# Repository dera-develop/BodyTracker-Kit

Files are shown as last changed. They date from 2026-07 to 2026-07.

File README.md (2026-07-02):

# BODY TRACKER  
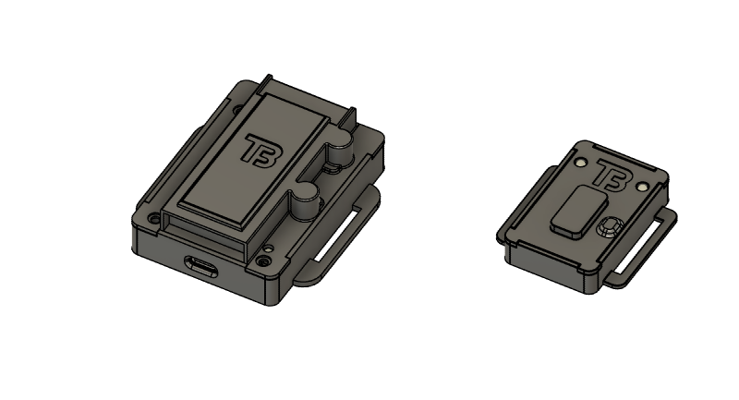
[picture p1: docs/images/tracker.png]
トラッカー
  
自作のトラッカーです．[SlimeVR](https://github.com/SlimeVR/SlimeVR-Server)を使用します．  
データの取得方法で迷走して，完成まで2か月くらいかかりました．  
ドリフトの時間サイクルは体感30分程度です．  

## 概要  
**LSM6DSV16X** のSFLPで出力されたクオータニオンを **ESP32-WROOM-32E** でI2C経由で拾ってSlimeVRに送信します．  

このトラッカーはマスターとスレーブの2個セットで製作されており，このセンサーを複数セット製作し接続することで，トラッキング箇所を自由に増やすことができます．  

詳細の仕様についてのドキュメントは[こちら](docs/overview.md)をご覧ください．  
製作手順については[こちら](docs/setup.md)をご覧ください．  

## 免責
本プロジェクトは以下の外部ソフトウェア・環境を利用しています．  
本リポジトリ内に同包はしていません．  
  
- SlimeVR Server  
[SlimeVR Server リポジトリ](https://github.com/SlimeVR/SlimeVR-Server)  
*本プロジェクトはSlimeVRのシステムと互換性を持つよう設計されていますが，SlimeVRチームによって作成，提供，または承認されたものではありません．*  
*「SlimeVR」は，SlimeVR BVの商標または登録商標です．*  
  
- Arduino  
[Arduino.cc](https://www.arduino.cc/)  
*本プロジェクトはArduino環境を利用していますが，Arduino公式プロジェクトとは無関係です．*  
*「Arduino(R)」は，Arduino Srlの商標または登録商標です．*

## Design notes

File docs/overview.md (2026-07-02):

# OVERVIEW  
トラッカーに関する詳細ドキュメントです．  

## 全体  
VRChatで使用することを前提として作成した，ボディートラッカーのセンサー2個セットです．  
モバイルバッテリー等の5V供給が出来るUSB電源を使用することで動作させることができます．  

製作する際は，[トラッカーの作り方](setup.md)を一読してください．製作手順と注意事項等が書いてあります．  

### 使用モジュール  
このトラッカーは，以下のIMUセンサーとマイコンを使用しています．  
|機器|名前|販売ページ(秋月電子通商)  
|---|---|---|
|IMUセンサー|LSM6DSV16X|[6軸IMUセンサーモジュール](https://akizukidenshi.com/catalog/g/g130950/)|  
|マイコン|ESP32-WROOM-32E|[ESP32-WROOM-32Eマイコンボード](https://akizukidenshi.com/catalog/g/g116108/)|  

表面実装が難しかったため，秋月電子通商で販売されているDPI化されているものを使用しています．  

### 構成  
構成は下図のようになっています．  
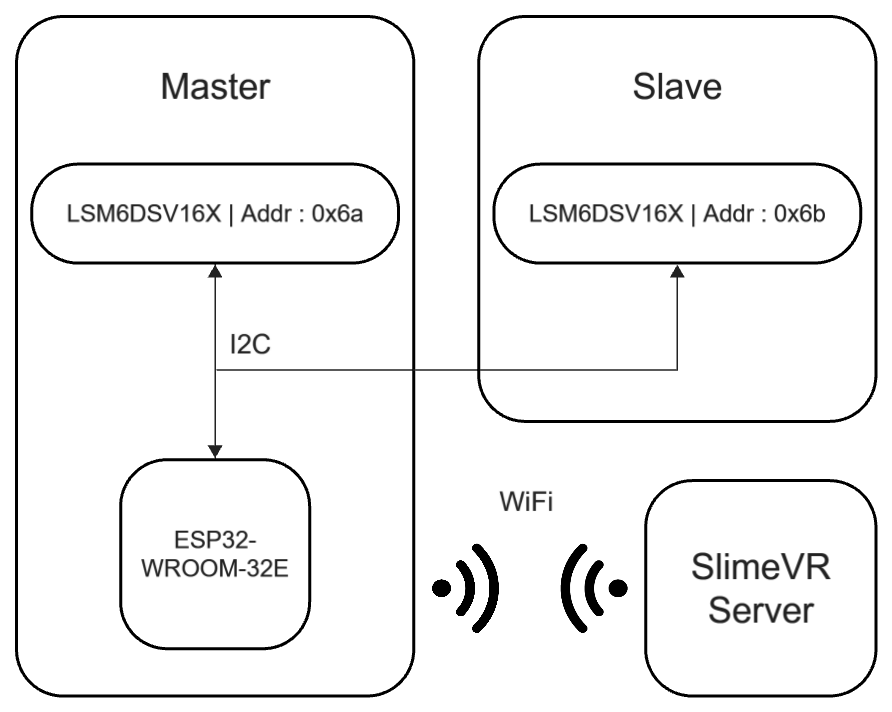
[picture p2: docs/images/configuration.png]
構成図
  

このトラッカーはマスターとスレーブに分かれており，I2Cで接続されています．  
相互の接続にはUSBのCtoCケーブルを使用します．  

#### プログラムの構成  
トラッカーのプログラムは，[prg/Firmware/BT_v4](../prg/Firmware/BT_v4/)に置いてあります．  
```  
BT_v4  
├── src/  
│   ├── I2Ccontroller.h  
│   ├── I2Ccontroller.cpp  
│   ├── IMUcontroller_I2C.h  
│   ├── IMUcontroller_I2C.cpp  
│   ├── Network_Connectioninfo_sample.h  
|   |     (実際のプログラムではNetwork_Connectioninfo.hを使用します)  
│   ├── UDPpackage.h  
│   └── UDPpackageV2.cpp  
└── BT_v4.ino  
```  
それぞれの内容は，ファイル名通りです．  
詳細は各ヘッダファイルを確認してください．  

### 動作  
電源スイッチが無く，USBケーブルを電源側に接続した時点で電源が入ります．  
（電源ポートとスレーブとの通信ポートは別物です．通信ポートに5Vを入力した場合，扱う電圧レベルが異なるため故障する可能性があります．）  
電源投入後，次の流れで動作します．  

#### 1, 初期設定  
始めにIMUセンサーの初期化を行います．IMUセンサー内にある **Who am I レジスタ(0x0f)** を参照し，値が読み取れた場合に初期化を行います．  
レジスタの初期化は，  
```  
prg/Firmware/BT_v4/src/IMUcontroller_I2C.cpp  
```  
内にある  
```cpp  
IMUcontroller_I2C::init(...)  
```  
関数内で実行されています．  
どのレジスタにどのデータを設定しているのかは，ここを参照することで確認できます．  

#### 2, WiFi接続  
プログラム内で設定されている情報を使い，WiFiネットワークに接続します．  
```cpp  
/* prg/Firmware/BT_v4/src/Network_Connectioninfo.h */  

namespace Network_ConnectionInfo{  
  inline constexpr char* WiFi_SSID = "WIFI_SSID";      // WiFi-SSID  
  inline constexpr char* WiFi_PASS = "WIFI_PASS";      // WiFi-PASS  
  ...  
}  
```  
同ディレクトリ内に **Network_Connectioninfo_sample.h** というファイルがあるので，このファイルの設定を変更し，名前を変更したうえで書き込みを行ってください．  

#### 3, サーバーハンドシェイク  
WiFiへ接続後，ハンドシェイクを送信します．  
```cpp  
/* prg/Firmware/BT_v4/src/Network_Connectioninfo.h */  

namespace Network_ConnectionInfo{  
  ...  
  inline constexpr char* SERVER_ADDR = "SERVER_IP_ADDRESS";    // SlimeVR-Server-IPAddress  
  inline constexpr int   SERVER_PORT = 6969;  // SlimeVR-Server-port  
}  
```  
ハンドシェイクパケットは2秒ごとに送信されます．（ステータスLEDの表示が約2000msのため）  
送信後ハンドシェイクACKを受信するまで繰り返されます．  

また，ハンドシェイクの試行回数は上限を設定でき，  
```cpp  
/* prg/Firmware/BT_v4/BT_v4.ino */  

const uint8_t   NW_WIFI_TIMEOUT = 100;  // WiFi timeout  
```  
で設定が可能です．最大値は **255** です．  
上限に達するとステータスLEDがエラー表示の点滅を行うようになり，それ以降の処理が行われません．  

#### 4, センサー情報の送信  
センサーの情報が送信されます．  

#### 5, センサーデータの送信  
ここがトラッキングのメインプロセスです．  
センサーの値を取得し，データをSlimeVR Serverへ送信します．  

FIFOの更新レートは120Hzに設定されており，新しいデータが届き次第パケットが送信されます．  

また，3秒ごとにステータスLEDが点滅します．

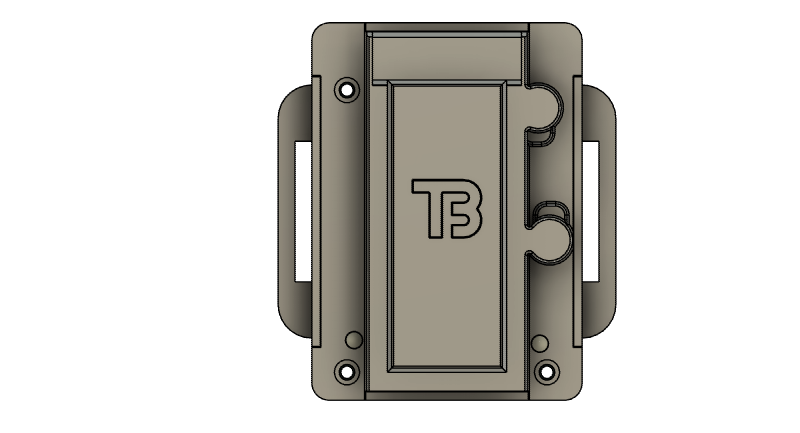
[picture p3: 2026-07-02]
docs/images/master_case_angle.png

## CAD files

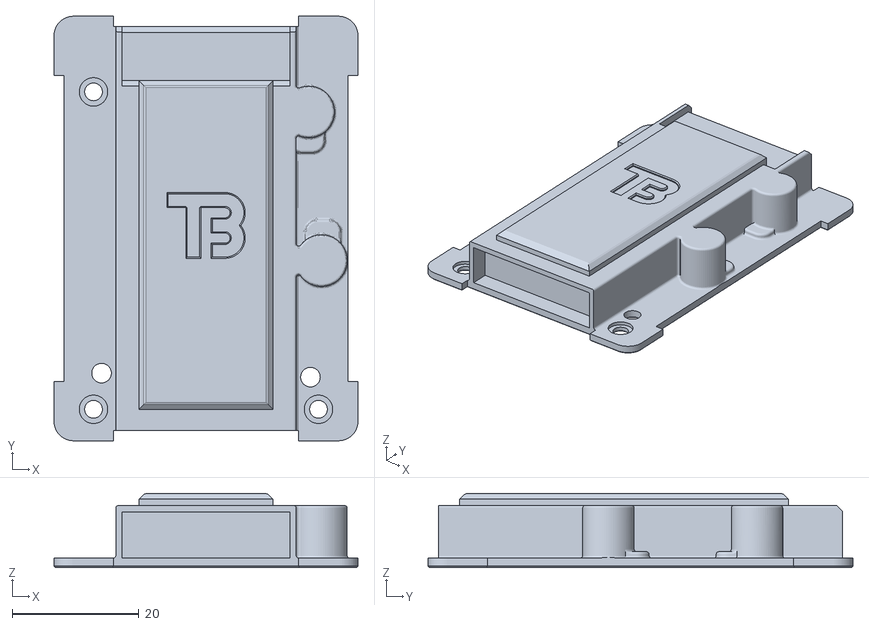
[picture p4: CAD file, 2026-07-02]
case/master/lid.stl
48.0 x 67.1 x 11.7

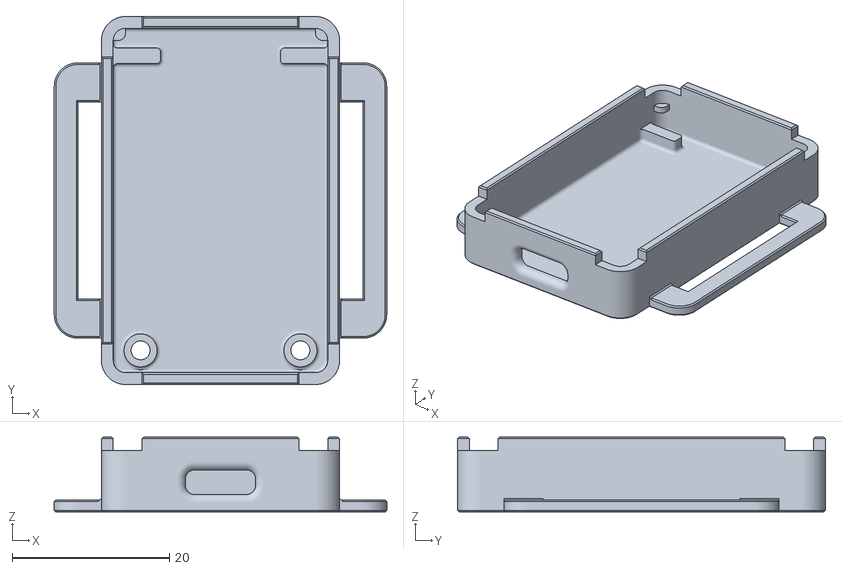
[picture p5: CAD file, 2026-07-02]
case/slave/box.stl
42.3 x 46.8 x 9.50

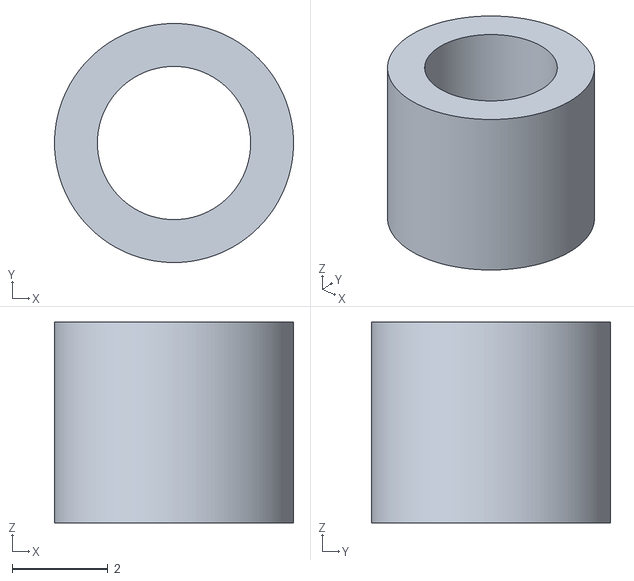
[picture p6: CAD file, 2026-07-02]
case/master/spacer.stl
5.00 x 5.00 x 4.20

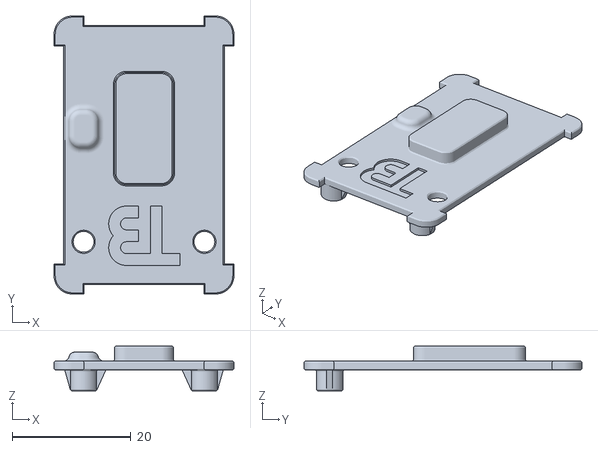
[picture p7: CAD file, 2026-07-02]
case/slave/lid.stl
30.3 x 46.8 x 7.50

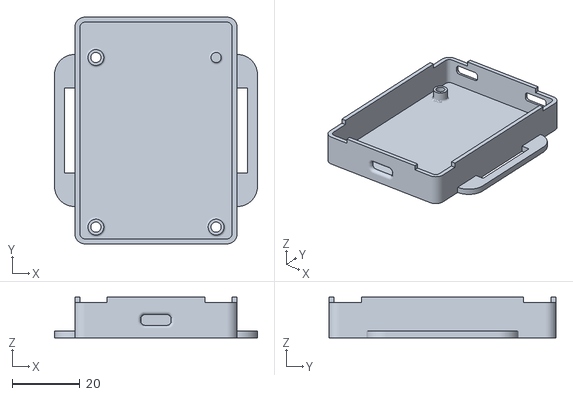
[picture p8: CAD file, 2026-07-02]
case/master/box.stl
60.0 x 67.1 x 12.0

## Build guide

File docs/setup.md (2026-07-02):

# トラッカーの作り方  
このトラッカーの作り方の手順を説明していきます．  

## 免責  
本ドキュメントに記載されているトラッカーの作成・使用・その他の利用によって生じた全ての損害，損失，トラブル等について，作者は一切の責任を負いません．また，いかなる保証やサポートも提供しません．  
本ツールの利用はすべて利用者自身の判断と責任において行ってください．  

## 必要なもの  
以下の部品を準備します．  
|名称|個数|販売ページ|  
|--|-:|--|
|ESP32-WROOM-32E|x1|[ESP32-WROOM-32E](https://akizukidenshi.com/catalog/g/g116108/)|  
|LSM6DSV16X|x1|[LSM6DSV16X](https://akizukidenshi.com/catalog/g/g130950/)|  
|ピンソケット 1x16p|x2|-|  
|電源専用USB-Cコネクタ|x2|[電源供給用TypeCコネクタ](https://akizukidenshi.com/catalog/g/g116895/)|  
|USB-Cコネクタ|x2|[ミッドマウントTypeCコネクタ](https://akizukidenshi.com/catalog/g/g113235/)|  
|φ3mm LED VF2.8 20mA|x4|-|  
|3.3V 3端子レギュレーター|x1|[3.3V-1A レギュレーター](https://akizukidenshi.com/catalog/g/g102252/)|  
|カーボン抵抗 1/4W 2kΩ|x4|-|  
|積層セラミックコンデンサ 0.1uF|x5|-|  
|アルミ電解コンデンサ 10uF|x1|-|  
|アルミ電解コンデンサ 47uF|x1|-|  

### PCB基板  
PCB基板を発注し，用意してください．  
必要数は，1セットそれぞれ1枚ずつです．  

- [マスターpcbデータ](../pcb/master/)  
- [スレーブpcbデータ](../pcb/slave_2.1/)  

それぞれにあるzipファイルへガーバーデータが入っています．JLCPCBへ発注する前提でデザインルールを設定しガーバーデータを生成したので，他へ発注する場合はガーバーデータの出力から行ってください．  

## 基板製作  
各PCB基板へ部品を取り付けます．  
### マスター基板  
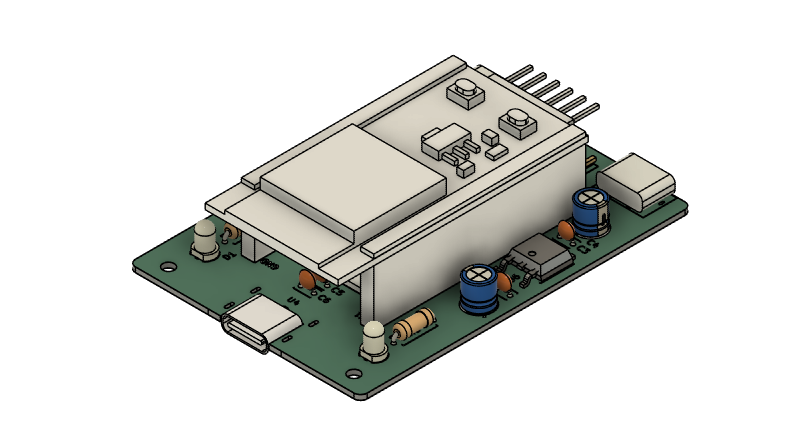
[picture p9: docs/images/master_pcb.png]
マスター基板
  

各部品を付ける場所は以下の通りです．  
|場所|部品名|  
|--|--|
|C1, C3, C5, C6|0.1uf 積層セラミックコンデンサ|  
|C2|47uF アルミ電解コンデンサ|  
|C4|10uF アルミ電解コンデンサ|  
|U1横の16ピン|ピンソケット 1x16p|  
|GND横の16ピン|ピンソケット 1x16p|  
|U2|LSM6DSV16X|  
|U3, U5|電源専用USB-Cコネクタ|  
|U4|USB-Cコネクタ|  
|U6|3.3V 3端子レギュレーター|  
|D1, D2|φ3mm LED VF2.8 20mA|  
|R1, R2|カーボン抵抗 1/4W 2kΩ|  

LEDの色を2色用意した場合は，D1が電源，D2が処理ステータスのLEDになっています．スレーブと合わせて取り付けてください．  

U4から取り付けることを強く推奨します．  
極性等に気を付けて取り付けてください．  
J1, R3, R4は使用しません．  

**⚠注意⚠**  
U2は，トラッカーを身に着ける向きに応じて取り付ける位置が変わります．  
LSM6DSV16Xモジュール基盤の白いコネクタが付いているほうを，身に着けるときの上側にして取り付けます．  
センサーモジュールのコネクタの位置を，基板上の白く塗りつぶされている位置に合わせてください．  

### スレーブ基板  
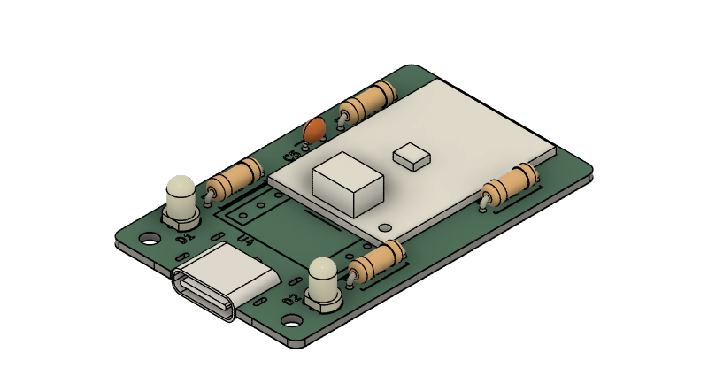
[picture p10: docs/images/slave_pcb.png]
スレーブ基板
  
|場所|部品名|  
|--|--|
|C5|0.1uf 積層セラミックコンデンサ|  
|U2|LSM6DSV16X|  
|U4|USB-Cコネクタ|  
|D1, D2|φ3mm LED VF2.8 20mA|  
|R1, R2|カーボン抵抗 1/4W 2kΩ|  

LEDの色は，マスターと同じくD1が電源，D2が処理ステータスのLEDです．  

**⚠注意⚠**  
U2は，こちらも同じくトラッカーを身に着ける向きに応じて取り付ける位置が変わります．  
LSM6DSV16Xモジュール基盤の白いコネクタが付いているほうを，身に着けるときの上側にして取り付けます．  
センサーモジュールのコネクタの位置を，基板上の白く塗りつぶされている位置に合わせてください．  

## ケース製作  
基板を収めるケースを製作します．  
3Dプリンターで製作します．  
- [マスターSTLファイル](../case/master/)  
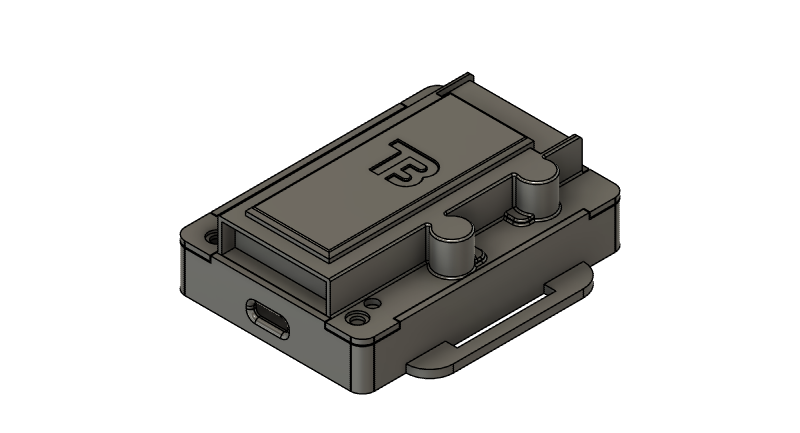
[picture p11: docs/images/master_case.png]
マスターケース
  
- [スレーブSTLファイル](../case/slave/)  
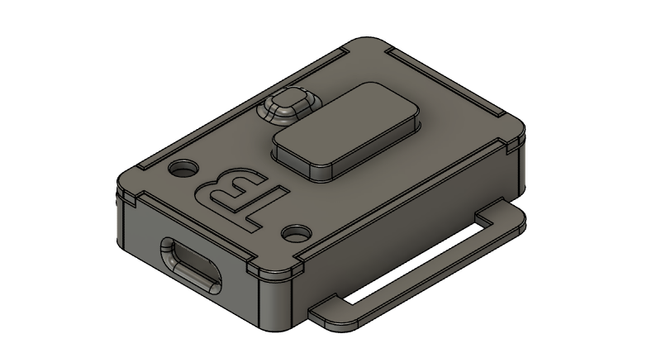
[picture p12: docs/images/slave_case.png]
スレーブケース
  

### マスター  
必要数は以下の通りです．  
|ファイル|個数|  
|--|--|
|[box.stl](../case/master/box.stl)|x1|  
|[lid.stl](../case/master/lid.stl)|x1|  
|[spacer.stl](../case/master/spacer.stl)|x3|  

印刷後，box.stlの図で示されている穴3か所にインサートナットを挿入してください．  
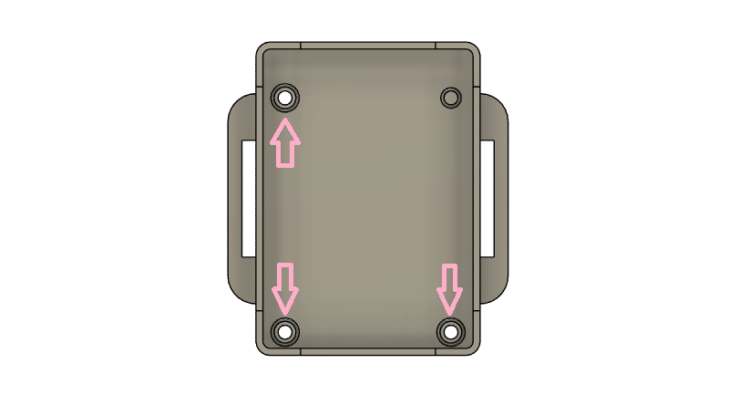
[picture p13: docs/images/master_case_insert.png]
マスターケース_インサートナット場所
  
M2のネジを使用するので，それに合わせてください．  

### スレーブ  
必要数は以下の通りです．  
|ファイル|個数|  
|--|--|
|[box.stl](../case/slave/box.stl)|x1|  
|[lid.stl](../case/slave/lid.stl)|x1|  

印刷後，lid.stlの図で示されている穴2か所にインサートナットを挿入してください．  
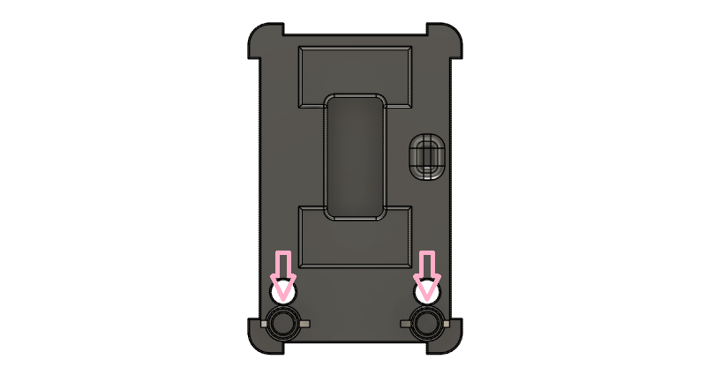
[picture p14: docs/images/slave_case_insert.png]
スレーブケース_インサートナット場所
  
マスターと同じくM2のネジを使用するので，それに合わせてください．  

## プログラムの書き込み  
ESP32へプログラムの書き込みを行います．  
### 設定  
プログラムを書き込む前に，ネットワーク設定を行います．  
プログラムファイルは[ここ](../prg/Firmware/BT_v4/)にあります．  
この中にある **Network_ConnectionInfo_sample.h** を変更します．  
自身の使用環境に合わせ，SSID, PASS, サーバーIPアドレスを設定してください．  
設定を行う前に，サーバーを動かすPCのIPアドレスを固定しておくことを強く推奨します．  
```cpp  
/* prg/Firmware/BT_v4/src/Network_ConnectionInfo_sample.h */  

namespace Network_ConnectionInfo{  
  inline constexpr char* WiFi_SSID = "";      // WiFi-SSID  
  inline constexpr char* WiFi_PASS = "";      // WiFi-PASS  
  inline constexpr char* SERVER_ADDR = "";    // SlimeVR-IPAddress  
  inline constexpr int   SERVER_PORT = 6969;  // SlimeVR-port  
}  
```  
設定が完了したら，ファイル名を **Network_ConnectionInfo.h** に変更してください．  
**名前の変更をしないと，コンパイル時にファイルが読み込まれずコンパイルエラーとなります．**  

### 書き込み  
シリアル変換モジュール等を使い，ArduinoIDEからプログラムを書き込みます．  
書き込むプログラムは，[ここ](../prg/Firmware/BT_v4/)にある **BT_v4.ino** です．  

**⚠注意⚠**  
**ESP32をマスター基板に取り付けた状態でシリアル変換モジュールを接続しないでください．**  
**レギュレーターへ3.3Vが逆流するため，レギュレーターが故障する可能性があります．**  

## 組み立て  
書き込みが終了したら，組み立てを行います．  

### マスター  
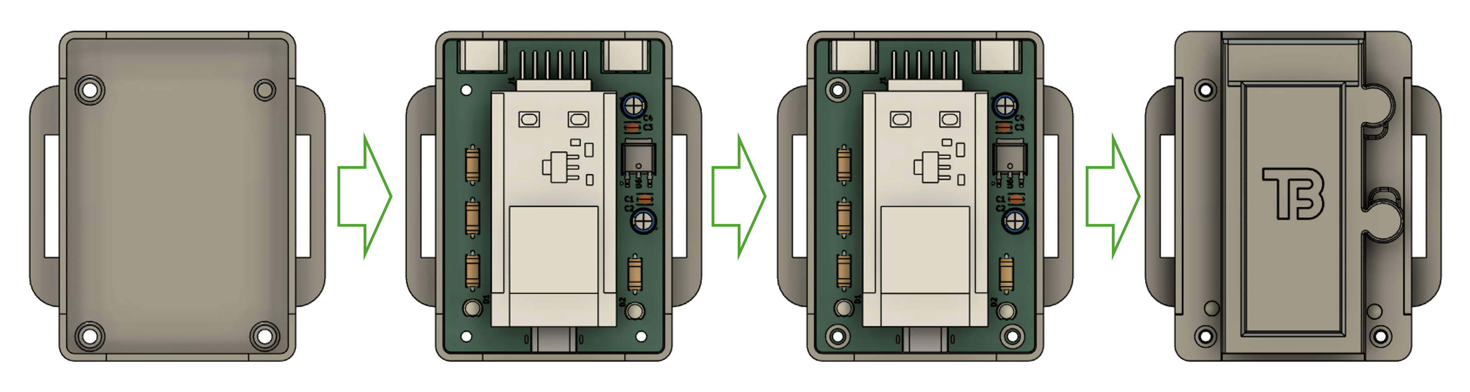
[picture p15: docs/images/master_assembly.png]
マスター組み立て手順
  
1. マスター基板にESP32をセットします．  
電源供給用TypeCポートがある方にESP32の書き込みコネクタが来るように差し込んでください．  
2. box.stlへ基板をはめ込みます．  
3. USBのポート数とケースに開いている穴の数を合わせてはめ込んでください．  
4. はめ込んだら，ねじ穴の3か所にspacer.stlを置きます．  
5. 蓋をかぶせます．  
6. 穴3か所を上からネジで止めます．  
M2のネジを使用します．ちょうど良い長さのものを選んでください．  

### スレーブ  
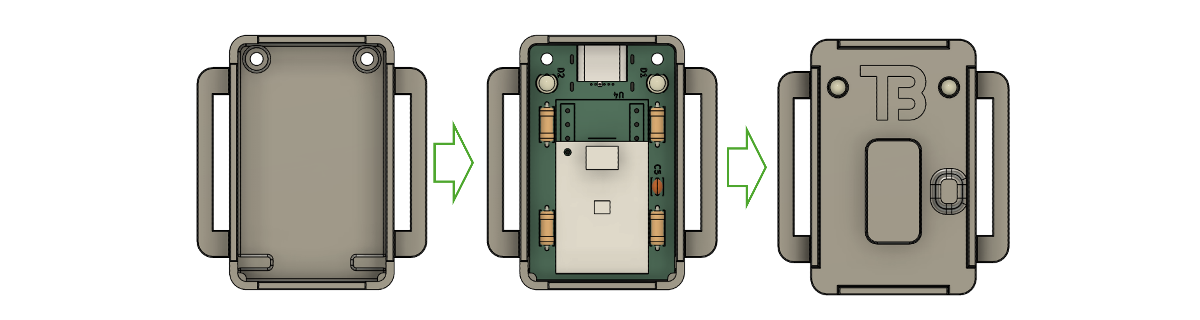
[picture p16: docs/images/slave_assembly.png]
スレーブ組み立て手順
  
1. box.stlへ基板をはめ込みます．  
ポートの向きに注意してください．  
2. 蓋をかぶせます．  
3. 穴2か所を下からネジで止めます．  
マスターと同じくM2のネジを使用します．  

## 接続  
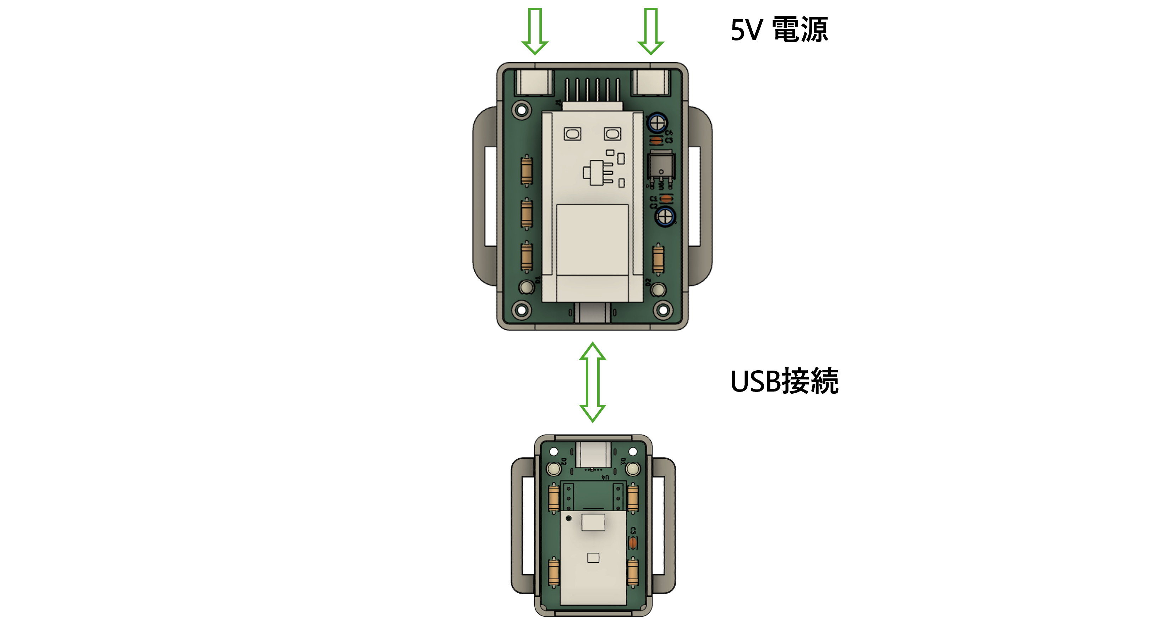
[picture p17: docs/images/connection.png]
接続
  
マスターとスレーブをCtoCケーブルで接続します．  
接続ケーブルは，USB3.2-Gen1以上の規格を推奨します．(USB3.0も対応しているとは思いますが，未検証です．)  
マスター基板の電源ポートに，5Vの電源を接続します．  
**PD対応のモバイルバッテリー等では電源の供給が出来ない可能性があります．Type-Aポートからの給電を推奨します．**  

電源スイッチがない為，電源ケーブルを接続した時点で電源が入りプログラムが走り始めます．  

### **⚠注意⚠**  
**マスターとスレーブを接続するTypeCポートは，これらの接続以外の接続は行わないでください．**  
**これらのポートの電源電圧は 3.3V です．もし誤って接続してしまった場合，過電圧によりマイコン・センサー・レギュレーターの故障に繋がります．**  
**また，コネクタとしてTypeCを使用しているだけであり通信規格は別物であるため，電源機器等の誤作動につながる可能性があります．**  

マスターとスレーブのケーブルには差し込む方向があります．間違っている場合はスレーブのステータスLEDが点灯するので，点灯していたら通信ケーブルのどちらかのコネクタを逆向きにして接続しなおし，電源を入れなおしてください．  

### 電源の共有について  
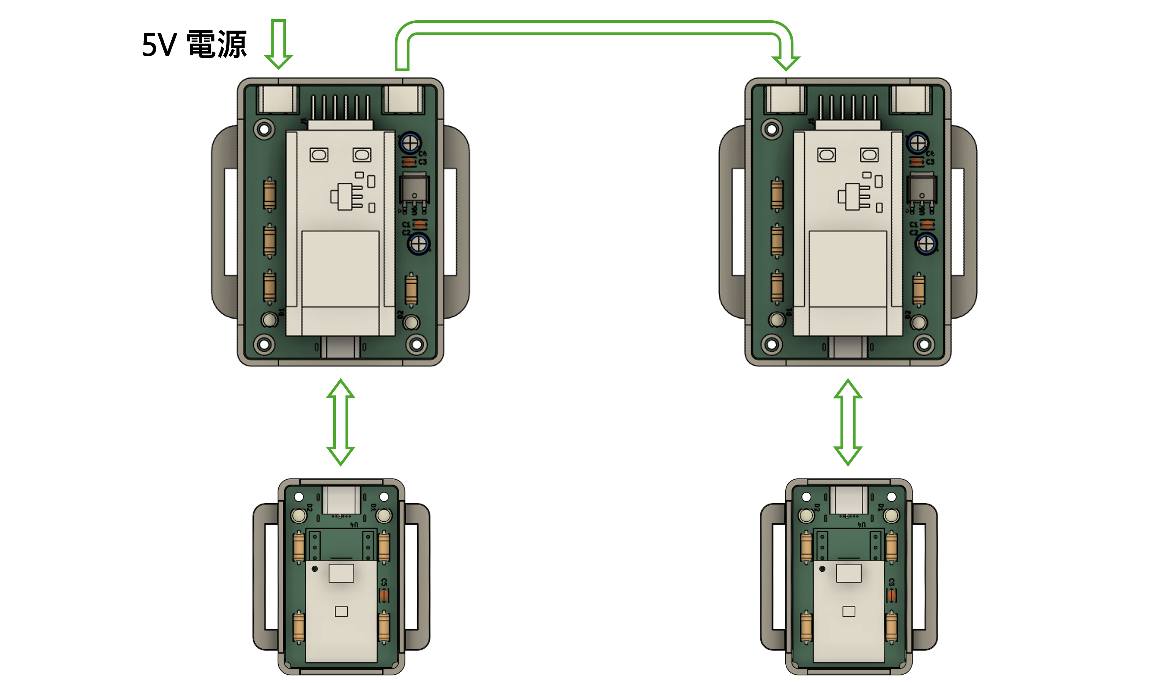
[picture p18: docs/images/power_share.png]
電源共有
  
電源ポートは内部で接続されており，電源を接続したポートではないほうのポートを別のマスターに接続することで，電源を共有することができます．  
そのため，このトラッカーセットを複数製作し接続することで，複数個所のトラッキングを１つの電源で行うことができます．  
（その分必要な電源容量が増加します）  

## 装着  
トラッカーは，ゴムバンド等を使用して装着します．  
100円ショップ等で販売されているゴムバンドが使用できると思います．  
ケースの両サイドにある四角の穴に通して使用するので，サイズが合うものを選んでください．  

## 利用時の注意点  
### 電源容量  
推奨電源は1セットにつき **2.5W 5V-500mA** です．  
レギュレーターの入力電圧は最大10Vまでサポートしますが，USB接続なので推奨は5Vです．  
使用するトラッカーの個数に合わせた電源を用意してください．  

### ケーブルの接続  
[接続セクション](#接続)でも記述しましたが，接続場所を誤ると，故障や発熱につながる恐れがあります．間違えないように気を付けてください．

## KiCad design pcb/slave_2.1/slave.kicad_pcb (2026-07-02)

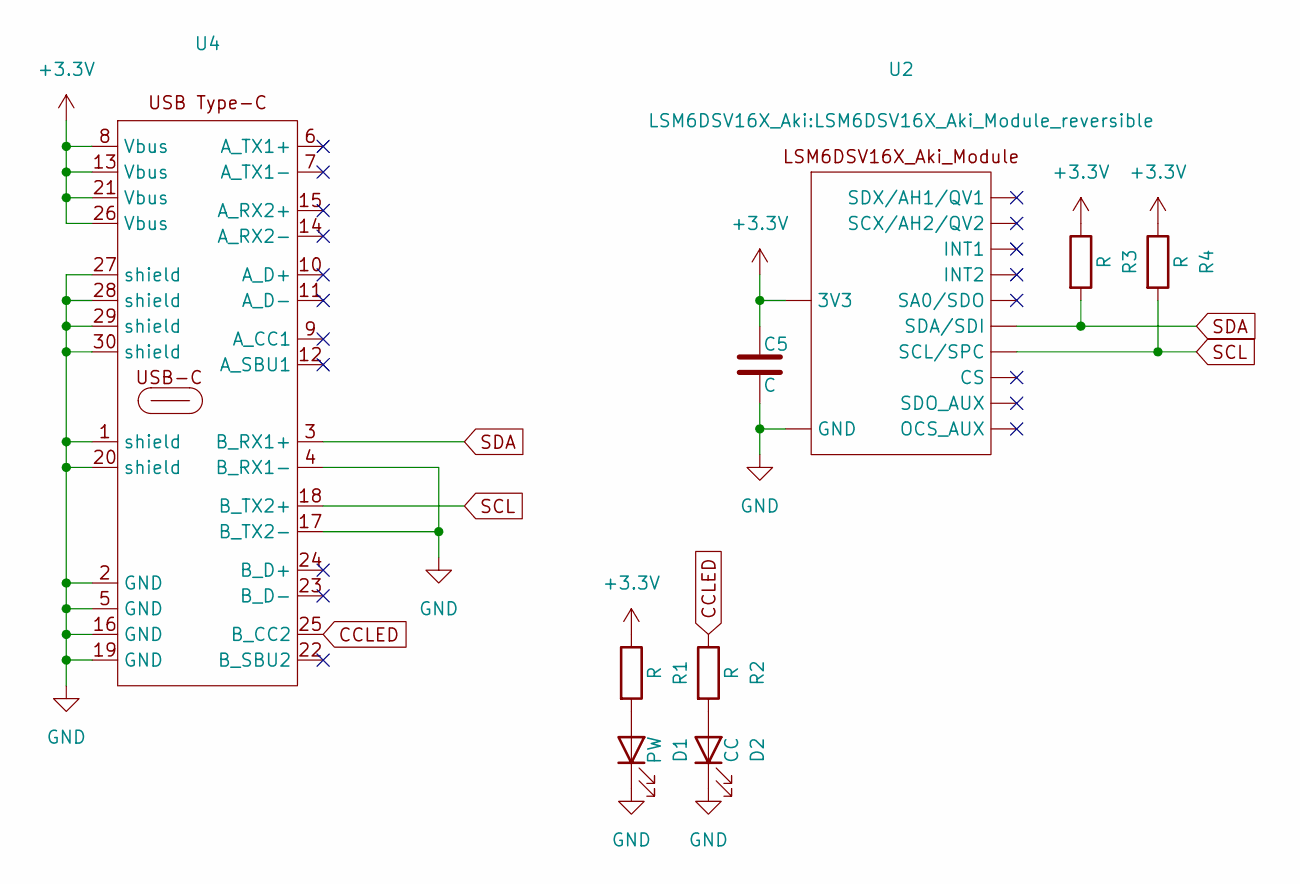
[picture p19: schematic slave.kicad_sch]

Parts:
C5: C; C_Disc_D3.0mm_W2.0mm_P2.50mm
D1: PW; LED_D3.0mm_Clear
D2: CC; LED_D3.0mm_Clear
R1, R2, R3, R4: R; R_Axial_DIN0207_L6.3mm_D2.5mm_P7.62mm_Horizontal
U2: LSM6DSV16X_Aki_Module_reversible
U4: JDC3-611479

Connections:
+3.3V: C5.1, R1.1, R3.1, R4.1, U2.6 (3V3), U4.8 (Vbus), U4.13 (Vbus), U4.21 (Vbus), U4.26 (Vbus)
CCLED: R2.1, U4.25 (B_CC2)
GND: C5.2, D1.1 (K), D2.1 (K), U2.5 (GND), U4.1 (shield), U4.2 (GND), U4.4 (B_RX1-), U4.5 (GND), U4.16 (GND), U4.17 (B_TX2-), U4.19 (GND), U4.20 (shield), U4.27 (shield), U4.28 (shield), U4.29 (shield), U4.30 (shield)
unnamed: D1.2 (A), R1.2
unnamed: D2.2 (A), R2.2
SCL: R4.2, U2.9 (SCL/SPC), U4.18 (B_TX2+)
SDA: R3.2, U2.8 (SDA/SDI), U4.3 (B_RX1+)

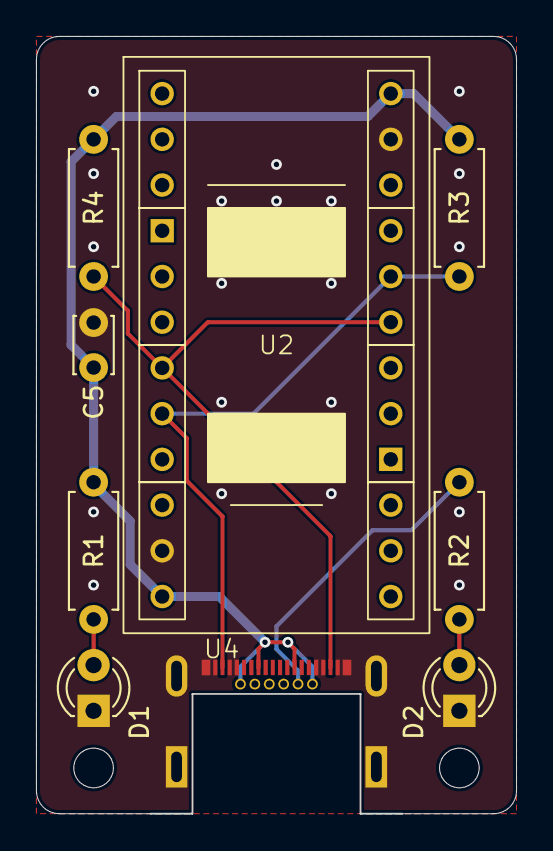
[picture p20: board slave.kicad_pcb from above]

Board: 2 copper layers, 26.7 x 43.2 mm, 9 parts (0 on the bottom side), 7 nets.

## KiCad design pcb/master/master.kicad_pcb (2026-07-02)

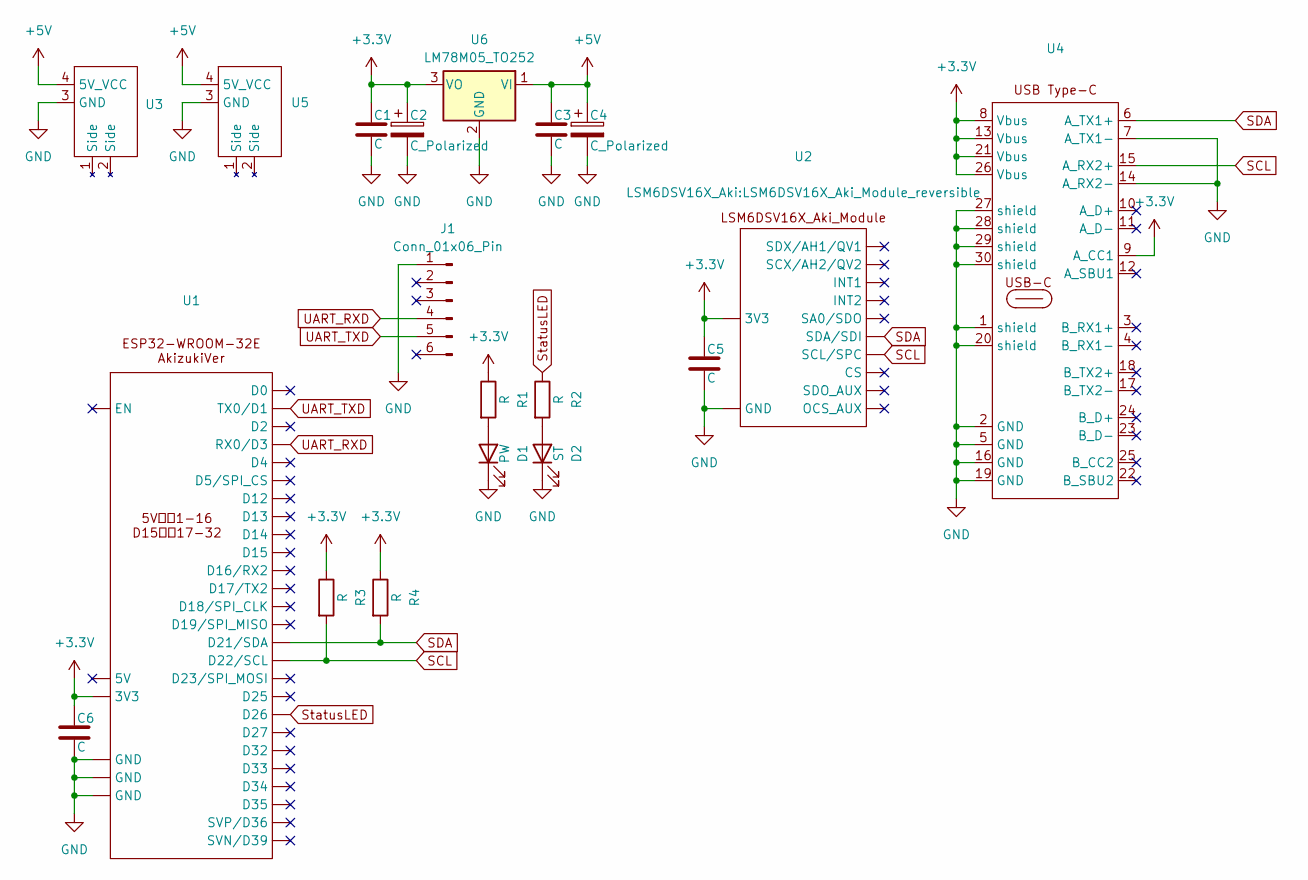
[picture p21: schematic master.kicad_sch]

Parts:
C1, C3, C5, C6: C; C_Disc_D3.0mm_W2.0mm_P2.50mm
C2, C4: C_Polarized; CP_Radial_D5.0mm_P2.00mm
D1: PW; LED_D3.0mm_Clear
D2: ST; LED_D3.0mm_Clear
J1: Conn_01x06_Pin; PinHeader_1x06_P2.54mm_Horizontal
R1, R2, R3, R4: R; R_Axial_DIN0207_L6.3mm_D2.5mm_P7.62mm_Horizontal
U1: ESP32-WROOM-32E_Aki
U2: LSM6DSV16X_Aki_Module_reversible
U3, U5: USB-TypeC_PowerOnly
U4: JDC3-611479
U6: LM78M05_TO252; TO-252-2

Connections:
+3.3V: C1.1, C2.1, C5.1, C6.1, R1.1, R3.1, R4.1, U1.16 (3V3), U2.6 (3V3), U4.8 (Vbus), U4.9 (A_CC1), U4.13 (Vbus), U4.21 (Vbus), U4.26 (Vbus), U6.3 (VO)
+5V: C3.1, C4.1, U3.4 (5V_VCC), U5.4 (5V_VCC), U6.1 (VI)
GND: C1.2, C2.2, C3.2, C4.2, C5.2, C6.2, D1.1 (K), D2.1 (K), J1.1, U1.3 (GND), U1.26 (GND), U1.32 (GND), U2.5 (GND), U3.3 (GND), U4.1 (shield), U4.2 (GND), U4.5 (GND), U4.7 (A_TX1-), U4.14 (A_RX2-), U4.16 (GND), U4.19 (GND), U4.20 (shield), U4.27 (shield), U4.28 (shield), U4.29 (shield), U4.30 (shield), U5.3 (GND), U6.2 (GND)
unnamed: D1.2 (A), R1.2
unnamed: D2.2 (A), R2.2
SCL: R3.2, U1.30 (D22/SCL), U2.9 (SCL/SPC), U4.15 (A_RX2+)
SDA: R4.2, U1.27 (D21/SDA), U2.8 (SDA/SDI), U4.6 (A_TX1+)
StatusLED: R2.1, U1.7 (D26)
UART_RXD: J1.4, U1.28 (RX0/D3)
UART_TXD: J1.5, U1.29 (TX0/D1)

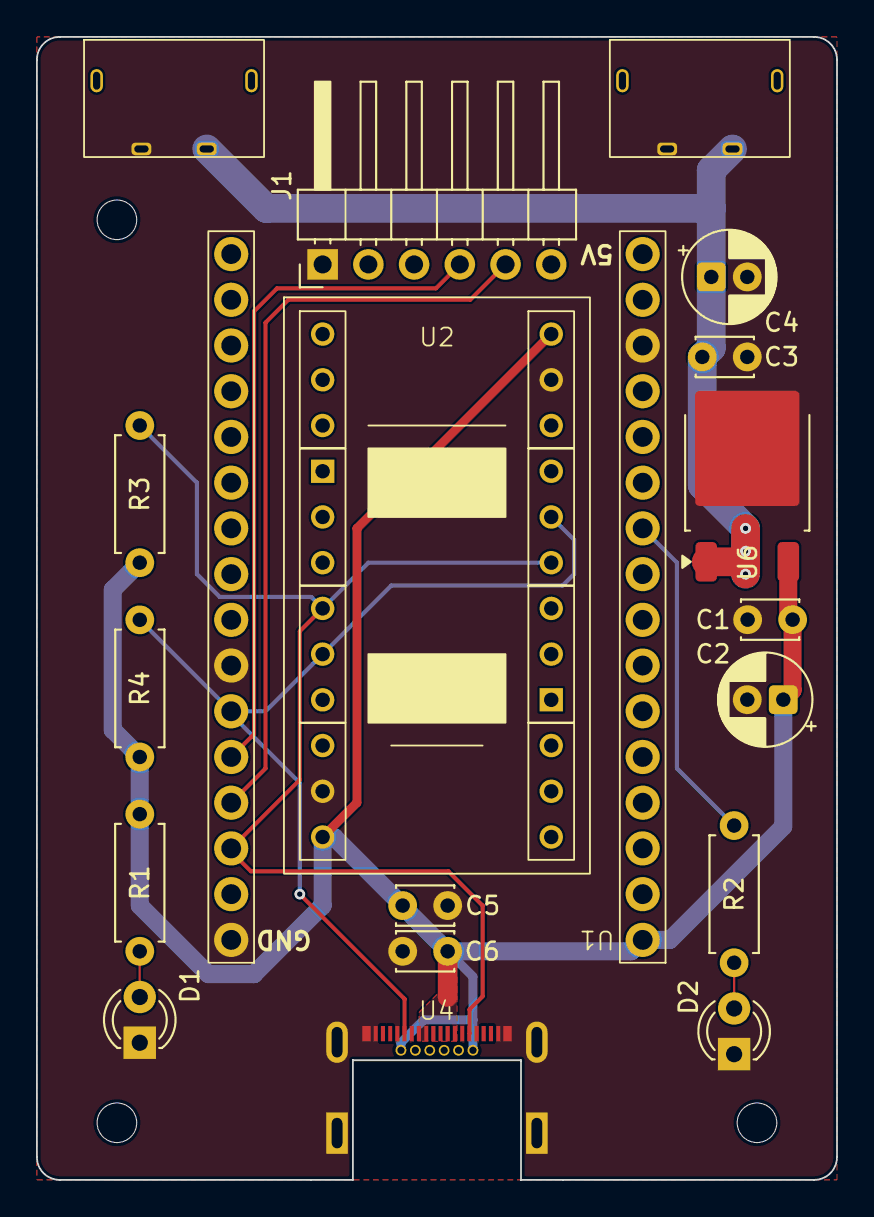
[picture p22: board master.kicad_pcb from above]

Board: 2 copper layers, 44.5 x 63.5 mm, 19 parts (0 on the bottom side), 10 nets.

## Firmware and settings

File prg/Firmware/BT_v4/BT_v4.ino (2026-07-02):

#include <Arduino.h>
#include <WiFi.h>
#include <WiFiUdp.h>

#include "src/I2Ccontroller.h"
#include "src/IMUcontroller_I2C.h"
#include "src/UDPpackage.h"

#include "src/Network_ConnectionInfo.h"

const uint8_t   ADDR_LSM6DSV16X_MASTER  = 0x6a;   // master sensor address
const uint8_t   ADDR_LSM6DSV16X_SLAVE   = 0x6b;   // slave sensor address
const uint8_t   PIN_STATUSLED           = 26;     // status LED digital pin
const uint32_t  I2C_CLOCK               = 400000; // I2C clock

// Network
const uint8_t   NW_WIFI_TIMEOUT = 100;  // WiFi timeout
const uint16_t  NW_UDP_PORT     = 8888; // use port number
WiFiUDP           NW_UDPcon;            // UDP controller
UDPpackageCreator NW_UDPpkger;          // UDP packager
uint64_t          NW_UDP_pkcnt;         // UDP packet counter
uint8_t           NW_MACADDRESS[6];     // device mac address

// LED controll timer
unsigned long lastMils;
unsigned long currentMils;

IMUcontroller_I2C IMUS_master;  // master sensor
IMUcontroller_I2C IMUS_slave;   // slave sensor

bool LED_changeLoopBlocker = false;

//////////////////////////////////////////////
/* Status                                   */
//////////////////////////////////////////////

/* status LED */
/*
  0: ERROR: IMU who am i
  1: init progress
  2: connecting WiFi
  3: connected WiFi
  4: WiFi connection timeout
  5: handshaking
  6: completed
*/
void statusLED(uint8_t statusID){
  switch(statusID){
    case 0:
      digitalWrite(PIN_STATUSLED, HIGH);
      delay(500);
      digitalWrite(PIN_STATUSLED, LOW);
      delay(500);
      digitalWrite(PIN_STATUSLED, HIGH);
      delay(250);
      digitalWrite(PIN_STATUSLED, LOW);
      delay(250);
      digitalWrite(PIN_STATUSLED, HIGH);
      delay(250);
      digitalWrite(PIN_STATUSLED, LOW);
      delay(250);
      break;
    
    case 1:
      digitalWrite(PIN_STATUSLED, HIGH);
      delay(250);
      digitalWrite(PIN_STATUSLED, LOW);
      delay(250);
      digitalWrite(PIN_STATUSLED, HIGH);
      delay(250);
      digitalWrite(PIN_STATUSLED, LOW);
      delay(250);
      break;
    
    case 2:
      digitalWrite(PIN_STATUSLED, HIGH);
      delay(500);
      digitalWrite(PIN_STATUSLED, LOW);
      delay(500);
      break;
    
    case 3:
      for(uint8_t i = 0;i < 3;i++){
        digitalWrite(PIN_STATUSLED, HIGH);
        delay(250);
        digitalWrite(PIN_STATUSLED, LOW);
        delay(250);
      }
      break;
    
    case 4:
      while(true){
        digitalWrite(PIN_STATUSLED, HIGH);
        delay(500);
        digitalWrite(PIN_STATUSLED, LOW);
        delay(500);
        digitalWrite(PIN_STATUSLED, HIGH);
        delay(500);
        digitalWrite(PIN_STATUSLED, LOW);
        delay(500);
        digitalWrite(PIN_STATUSLED, HIGH);
        delay(250);
        digitalWrite(PIN_STATUSLED, LOW);
        delay(250);
      }
      break;
    
    case 5:
      digitalWrite(PIN_STATUSLED, HIGH);
      delay(500);
      digitalWrite(PIN_STATUSLED, LOW);
      delay(500);
      digitalWrite(PIN_STATUSLED, HIGH);
      delay(100);
      digitalWrite(PIN_STATUSLED, LOW);
      delay(900);
      break;
    
    case 6:
      for(uint8_t i = 0;i < 3;i++){
        digitalWrite(PIN_STATUSLED, HIGH);
        delay(300);
        digitalWrite(PIN_STATUSLED, LOW);
        delay(300);
      }
      break;
    
    default:
      break;
  }
}

//////////////////////////////////////////////
/* Network                                  */
//////////////////////////////////////////////

// init
void Init_Network(){
  WiFi_Connection();
  WiFi.macAddress(NW_MACADDRESS);
}

// WiFi connection
void WiFi_Connection(){
  WiFi.begin(Network_ConnectionInfo::WiFi_SSID, Network_ConnectionInfo::WiFi_PASS);
  uint8_t ConnectionCount = 0;
  while(WiFi.status() != WL_CONNECTED){
    statusLED(2);
    if(ConnectionCount++ > NW_WIFI_TIMEOUT){
      Serial.println("Failed. | WiFi connection timeout");
      statusLED(4);
    }
  }
  statusLED(3);

  NW_UDPcon.begin(NW_UDP_PORT);
}

// send UDP package
void UDP_SendPackage(UDPpackageCreator& SendObject){
  NW_UDPcon.beginPacket(Network_ConnectionInfo::SERVER_ADDR, Network_ConnectionInfo::SERVER_PORT);
  NW_UDPcon.write(SendObject.getUDPdatas(), SendObject.getSize());
  NW_UDPcon.endPacket();
}

// handshake(ID:3)
void UDP_SendHandShake(){
  NW_UDPpkger.reset();
  NW_UDPpkger.addUint32(3);    // packetID
  NW_UDPpkger.addUint64(0);    // packet number
  NW_UDPpkger.addUint32(3);    // board type
  NW_UDPpkger.addUint32(14);   // imu type
  NW_UDPpkger.addUint32(2);    // mcu type
  uint8_t brankData[12] = {0};
  NW_UDPpkger.addBytes(brankData, 12);
  NW_UDPpkger.addUint32(5);    // firmware build
  NW_UDPpkger.addString("IMU_Tracker_V3.1"); // name
  NW_UDPpkger.addBytes(NW_MACADDRESS, 6);  // mac address

  UDP_SendPackage(NW_UDPpkger);
}

// handshake ack checker
bool UDP_CheckHandShakeACK(){
  int RecvPackageSize = NW_UDPcon.parsePacket();
  if(RecvPackageSize > 0){
    uint8_t recvBuf[128];
    NW_UDPcon.read(recvBuf, 128);

    return recvBuf[0] == 3;
  }
  return false;
}

// sensor infomation(ID:15)
void UDP_SendSensorInfo(IMUcontroller_I2C& IMU){
  NW_UDPpkger.reset();
  NW_UDPpkger.addUint32(15);   // packetID
  NW_UDPpkger.addUint64(NW_UDP_pkcnt++);   // packet number
  NW_UDPpkger.addUint8(IMU.sensorID);  // sensorID
  NW_UDPpkger.addUint8(1);     // sensor status
  NW_UDPpkger.addUint8(14);    // sensor type

  UDP_SendPackage(NW_UDPpkger);
}

// sensor data(ID:17)
void UDP_SendSensorData(IMUcontroller_I2C& IMU){
  NW_UDPpkger.reset();
  NW_UDPpkger.addUint32(17);
  NW_UDPpkger.addUint64(NW_UDP_pkcnt++);
  NW_UDPpkger.addUint8(IMU.sensorID);
  NW_UDPpkger.addUint8(1);
  for(uint8_t i = 1;i < 4;i++)  NW_UDPpkger.addFloat(IMU.quaternions[i]);
  NW_UDPpkger.addFloat(IMU.quaternions[0]);
  NW_UDPpkger.addUint8(0);

  UDP_SendPackage(NW_UDPpkger);
}

//////////////////////////////////////////////
/* other                                    */
//////////////////////////////////////////////

// int8_t -> hex (debug)
void Serial_PrintHex(uint8_t value){
  if(value < 16)  Serial.print('0');
  Serial.print(value, HEX);
}

//////////////////////////////////////////////
/* setup                                    */
//////////////////////////////////////////////
void setup(){
  Serial.begin(115200);
  while(!Serial);

  Serial.println("\n\n");
  Serial.println("== Body Tracking system v3.1 ==");

  pinMode(PIN_STATUSLED, OUTPUT);

  I2Ccon_init_I2C(I2C_CLOCK);

  // init sensor
  Serial.println("task: init IMU sensor");
  // sensor
  Serial.println("IMU_master | init... ");
  if(!IMUS_master.init(0, ADDR_LSM6DSV16X_MASTER)){
    Serial.println("Failed");
    while(true) statusLED(0);
  }
  Serial.println("OK.");

  // sensor
  Serial.println("IMU_slave  | init... ");
  if(!IMUS_slave.init(1, ADDR_LSM6DSV16X_SLAVE)){
    Serial.println("Failed");
    while(true) statusLED(0);
  }
  Serial.println("OK");

  // init network
  Serial.println("task: init Network");
  WiFi.macAddress(NW_MACADDRESS);
  Serial.print("device MACADDRESS: ");
  for(uint8_t i = 0;i < 6;i++){
    Serial_PrintHex(NW_MACADDRESS[i]);
    if(i < 5) Serial.print(':');
  }
  Serial.println();

  // wifi connection
  Serial.print("connecting WiFi network... ");
  WiFi_Connection();
  Serial.println("OK.");

  Serial.println("init completed!");
}

//////////////////////////////////////////////
/* main                                     */
//////////////////////////////////////////////
uint8_t StateLevel = 1;
void loop(){
  switch(StateLevel){
    case 1:
      // handshake
      Serial.println("task: server handshake");
      while(true){
        Serial.print("send handshake packet");
        UDP_SendHandShake();
        Serial.print(" | waiting ACK... ");
        statusLED(5);
        if(UDP_CheckHandShakeACK()){
          Serial.println("Received.");
          statusLED(6);
          StateLevel++;
          break;
        }
        Serial.println("Timeout.");
      }
      break;
    
    case 2:
      // send sensor infomations
      Serial.println("task: send sensor infomation packet");
      UDP_SendSensorInfo(IMUS_master);
      UDP_SendSensorInfo(IMUS_slave);
      StateLevel++;
      Serial.println("task: tracking and send quaternion to server");
      lastMils = millis();
      break;
    
    case 3:
      // get and send sensor datas
      currentMils = millis();

      if(IMUS_master.getQuaternions()) UDP_SendSensorData(IMUS_master);
      if(IMUS_slave.getQuaternions())  UDP_SendSensorData(IMUS_slave);

      if(currentMils - lastMils > 3000 && !LED_changeLoopBlocker){
        digitalWrite(PIN_STATUSLED, HIGH);
        LED_changeLoopBlocker = true;
      }
      if(currentMils - lastMils > 3100){
        digitalWrite(PIN_STATUSLED, LOW);
        LED_changeLoopBlocker = false;
        lastMils = millis();
      }
      break;
  }
}

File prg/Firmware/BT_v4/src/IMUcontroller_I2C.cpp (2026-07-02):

#include <Arduino.h>
#include "IMUcontroller_I2C.h"
#include "I2Ccontroller.h"

#define   ADDR_FUNC_CFG_ACCESS  0x01

#define   ADDR_EMB_FUNC_EN_A      0x04
#define   ADDR_EMB_FUNC_FIFO_EN_A 0x44
#define   ADDR_SFLP_ODR           0x3e

#define   ADDR_FIFO_CTRL2 0x08
#define   ADDR_FIFO_CTRL3 0x09
#define   ADDR_FIFO_CTRL4 0x0a

#define   ADDR_WHOAMI     0x0f

#define   ADDR_FIFO_STATUS1       0x1b
#define   ADDR_FIFO_STATUS2       0x1c
#define   ADDR_FIFO_DATA_OUT_TAG  0x78

#define   TAG_QUATERNION  0x13

#define   ADDR_CTRL1      0x10
#define   ADDR_CTRL2      0x11
#define   ADDR_CTRL3      0x12
#define   ADDR_STATUS     0x1e

#define   MASK_BOOTSTATUS 0x08


float halfToFloat(uint16_t halfFloat) {
  uint32_t sign = (halfFloat >> 15) & 1;
  uint32_t exp = (halfFloat >> 10) & 0x1F;
  uint32_t mantissa = halfFloat & 0x3FF;

  if (exp == 0) {
    if (mantissa == 0) return sign ? -0.0f : 0.0f;
    while (!(mantissa & 0x400)) {
      mantissa <<= 1;
      exp--;
    }
    exp++;
    mantissa &= ~0x400;
  } else if (exp == 31) {
    return 0.0f;
  }
  exp = exp + (127 - 15);
  uint32_t floatBits = (sign << 31) | (exp << 23) | (mantissa << 13);
  float result;
  memcpy(&result, &floatBits, 4);
  return result;
}

IMUcontroller_I2C::IMUcontroller_I2C(){}

bool IMUcontroller_I2C::init(uint8_t setSensorID, uint8_t setDeviceAddress, bool checkWAI){
  deviceAddress = setDeviceAddress;
  sensorID = setSensorID;
  if(I2Ccon_getData(deviceAddress, ADDR_WHOAMI) != 0x70 && checkWAI) return false;
  while(true){
    if((I2Ccon_getData(deviceAddress, ADDR_STATUS) & MASK_BOOTSTATUS) == 0) break;
    delay(100);
  }
  I2Ccon_setData(deviceAddress, ADDR_CTRL3, 0x01);
  delay(50);
  I2Ccon_setData(deviceAddress, ADDR_CTRL3, 0x44);
  I2Ccon_setData(deviceAddress, ADDR_FIFO_CTRL2, 0x00);
  I2Ccon_setData(deviceAddress, ADDR_FIFO_CTRL3, 0x00);
  I2Ccon_setData(deviceAddress, ADDR_FIFO_CTRL4, 0x06);
  I2Ccon_setData(deviceAddress, ADDR_FUNC_CFG_ACCESS, 0x80);
  delay(10);
  I2Ccon_setData(deviceAddress, ADDR_EMB_FUNC_EN_A, 0x02);
  I2Ccon_setData(deviceAddress, ADDR_EMB_FUNC_FIFO_EN_A, 0x22);
  I2Ccon_setData(deviceAddress, ADDR_SFLP_ODR, 0x03);
  I2Ccon_setData(deviceAddress, ADDR_FUNC_CFG_ACCESS, 0x00);
  delay(10);
  I2Ccon_setData(deviceAddress, ADDR_CTRL1, 0x64);
  I2Ccon_setData(deviceAddress, ADDR_CTRL2, 0x6c);
  delay(100);
  return true;
}

bool IMUcontroller_I2C::getQuaternions(){
  uint8_t fifoStatus1 = I2Ccon_getData(deviceAddress, ADDR_FIFO_STATUS1);
  uint8_t fifoStatus2 = I2Ccon_getData(deviceAddress, ADDR_FIFO_STATUS2);
  uint16_t fifo_nowBuf = fifoStatus1 | ((fifoStatus2 & 0x01) << 8);

  if(fifo_nowBuf > 0){
    uint8_t fifo_buf[7];
    I2Ccon_getDatas(deviceAddress, ADDR_FIFO_DATA_OUT_TAG, fifo_buf, 7);
    
    uint8_t tag = (fifo_buf[0] >> 3) & 0x1f;

    if(tag == TAG_QUATERNION){
      uint16_t qx = fifo_buf[1] | (fifo_buf[2] << 8);
      uint16_t qy = fifo_buf[3] | (fifo_buf[4] << 8);
      uint16_t qz = fifo_buf[5] | (fifo_buf[6] << 8);

      quaternions[1] = halfToFloat(qx);
      quaternions[2] = halfToFloat(qy);
      quaternions[3] = halfToFloat(qz);
      float w_sum = quaternions[1]*quaternions[1] + quaternions[2]*quaternions[2] + quaternions[3]*quaternions[3];
      if(w_sum <= 1.0f) quaternions[0] = sqrt(1.0f - w_sum);
      else              quaternions[0] = 0.0f;
      return true;
    }
  }
  return false;
}

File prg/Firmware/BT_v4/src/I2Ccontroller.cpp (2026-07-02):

#include <Arduino.h>
#include <Wire.h>

void I2Ccon_init_I2C(uint32_t I2C_clock){
  delay(50);
  Wire.begin();
  Wire.setClock(I2C_clock);
  delay(50);
}

uint8_t I2Ccon_getData(uint8_t deviceAddress, uint8_t targetAddress){
  Wire.beginTransmission(deviceAddress);
  Wire.write(targetAddress);
  Wire.endTransmission(false);
  Wire.requestFrom(deviceAddress, 1);
  while (Wire.available()){
    return Wire.read();
  }
}

void I2Ccon_getDatas(uint8_t deviceAddress, uint8_t targetAddress, uint8_t* buffer, uint8_t dataLength){
  Wire.beginTransmission(deviceAddress);
  Wire.write(targetAddress);
  Wire.endTransmission(false);
  Wire.requestFrom(deviceAddress, dataLength);
  for(uint8_t i = 0;i < dataLength;i++){
    buffer[i] = Wire.read();
  }
}

void I2Ccon_setData (uint8_t deviceAddress, uint8_t targetAddress, uint8_t setValue){
  Wire.beginTransmission(deviceAddress);
  Wire.write(targetAddress);
  Wire.write(setValue);
  Wire.endTransmission();
}
